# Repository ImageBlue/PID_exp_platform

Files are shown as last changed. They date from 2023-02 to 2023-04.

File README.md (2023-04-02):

# PID_exp_platform
## 某小组的大创项目

项目名称：基于开源硬件的水下推进器PID实验平台
A PID experiment platform based on open-sourced hardware.

## 项目的代码主要分为两部分：

### 上位机：OController

主要功能：显示实时流速（流速以推进器产生的水流冲击挡板，使挡板产生的**偏角**为依据）、与下位机有线或无线连接、对下位机PID参数和目标流速的设置

上位机的可运行程序已上传至项目的release，提供Windows版和DawningW第三方打包的MacOS版

### 下位机：

主要功能：控制推进器、响应上位机发来的请求  
下位机主要由外壳、shield、Arduino UNO、ESP32等各模块组成  
shield连接各个模块，~~外壳则进行保护包装~~  
下位机详见uno、esp32、shell、PCB文件夹

## 项目作者：

[*ImageBlue*](https://github.com/ImageBlue)

[*Bismark-bugger*](https://github.com/Bismark-bugger)

[*Silicon-t*](https://github.com/Silicon-t)

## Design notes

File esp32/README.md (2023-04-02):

大创项目的下位机  

该部分为esp32代码  
外设连接：推进器-D4   软串口-D23,D22   USB-TTL模块(不必须)-TXD,RXD,5V   串口   

*进度  
2023/2/10  完成与uno的软串口通讯测试，完成串口助手的通讯测试，完成MQTT基础通讯测试（未写入），完成推进器的驱动测试（未写入）  
2023/2/13  完成PID算法的移植，完成与上位机的串口初步调试，完成串口指令识别操作，完成推进器控制补充   
2023/3/6  完成MQTT代码移植，完成连接模式检查逻辑的编写，完成PID实机水下测试，完成与上位机包括MQTT和串口的完整通讯测试  
2023/4/3  卧槽版本大更新，但应该是最终版，~~鬼知道我们经历了什么~~

*更新日志  
2023/2/10  
-上传文件  核心代码：esp32_pro  硬件/软件串口模块：usart  软串口SoftwareSerial库：SoftwareSerial.h/.cpp  
完成与UNO的软串口连接通讯，可以接收并处理UNO发送的原始流速数据，真实流速值精确到0.01  
完成硬件串口通讯，此处用的是XCOM串口助手，可以进行发送实时流速值与接收设定的目标流速  
！！！！！注意：流速值指令格式 VELO int ，此处int为至多五位的整形，该值为实时流速值×100后的值，上位机接收时注意处理  
设定目标流速指令格式 VELO int ,此处int为至多三位的整形  
2023/2/13  
-上传文件  PID功能操作：command.ino  自创PID库文件：pid.h/.cpp（创建者[*Silicon-t*](https://github.com/Silicon-t)）  
-更新文件  核心代码：esp32_pro.ino  硬件/软件串口模块：usart.ino  
完成自创PID库的移植，采用C++编写，高度封装，PID流程已打包完成，使用command的run_pid函数即可  
加入推进器的控制，很简单，PWM输出即可  
更新串口指令识别，可以识别指令：手动自动切换、PID参数接收与处理，与上位机实现初步通讯测试  
优化了与UNO的软串口通讯的接收功能，用以解决随机出现的LoadStoreError  
2023/3/6  
-上传文件  MQTT驱动代码：mqtt_pro.ino  
-更新文件  核心代码：esp32_pro.ino  硬件/软件串口模块：usart.ino  
优化了PID参数更改指令的处理流程，解决了PID参数无法正常更改的重大bug  
完成MQTT部分代码移植，可以实现MQTT服务器连接、实时流速上传与上位机指令控制，指令格式与串口完全一致   
！！！！！注意：需要先启动树莓派的MQTT服务器终端，树莓派端使用的是mosquitto库，当然要是自己搭建了MQTT服务器终端  
！！！！！注意：使用时先改代码中mqtt_pro.ino的wifi账号与密码、MQTT服务器的IP与端口号，ESP32与服务器终端务必在一个局域网内   
ESP32启动后会进行连接方式检测，会进行MQTT与串口的轮询检测，对应的Connect指示灯会闪烁  
如果进行串口连接，请打开上位机后等待ESP32识别；如果进行MQTT连接，启动服务器后等待即可  
优化了回传实时流速的指令生成部分，便于调用，节约资源  
PID算法初步实机实验，算法在跑但跑的不是特别好，将会改进  
！！！！！注意：推进器由外部24V电源供电，请勿连接ESP32的3V3引脚，会导致ESP32损坏  
后续计划加入更多的指示灯与连接重置按键，敬请期待下次更新

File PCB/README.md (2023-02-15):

大创项目的shield设计文件  
包含：lcd_shield，board_shield  
使用立创EDA设计  

*立创eda打开方式  
解压嘉立创工程文件，里面有原理图与PCB的.json文件  
打开编辑器，通过：顶部菜单 - 文件 - 打开 - 立创EDA... ，选择 json 文件打开在编辑器，你可以保存文档进工程里面。

*进度   
2023/2/10   完成设计与焊接  

*更新日志  
2023/2/10  
上传文件  嘉立创工程文件：bjut_v2_20230210,bjut_v2_20230210  制板文件：Gerber_bjuts_v2,Gerber_PCB_lcd_tr  
bjut_v2：board_shield ，实现uno、esp、yf-s201、推进器等模块连接，注意5V供电  
lcd_tr：lcd_shield，实现LCD-1602连接，与board_shield的lcd排母对应，lcd的VL与可变电阻相连  

*BOM清单  
bjuts_v2：

| | Name | Designator | Footprint | Quantity |
| ---- | --- | --- | --- | --- |
| 1 | DC005-2.0MM | DC1 | DC-IN-TH_DC005 | 1 |
| 2 | 180Ω | R3 | R1206 | 1 |
| 3 | FC-2012UGK-520D5 | LED1 | LED0805-R-RD | 1 |
| 4 | PM254-1-16-Z-8.5 | LCD | HDR-TH_16P-P2.54-V-F-A | 1 |
| 5 | Header-Male-2.54_1x3  | YF-S201,P  | HDR-TH_3P-P2.54-V-M-1  | 2 |
| 6 | DSWB01LHGET | SW1 | SW-TH_DSWB01LHGET | 1 |
| 7 | 2.54-1*4P母 | USB-TTL | HDR-TH_4P-P2.54-V-F | 1 |
| 8 | Header-Male-2.54_1x10 | H3 | HDR-TH_10P-P2.54-V-M-1 | 1 |
| 9 | Header-Male-2.54_1x8  | H4,H5 | HDR-TH_8P-P2.54-V-M | 2 |
| 10 | Header-Male-2.54_1x6  | H6 | HDR-TH_6P-P2.54-V-M-1  | 1 |
| 11 | PM254-1-15-Z-8.5 | U2,U3 | HDR-TH_15P-P2.54-V-F | 2 |

lcd_tr：

| ID | Name | Designator | Footprint | Quantity |
| ---- | --- | --- | --- | --- |
| 1 | X6511WV-16H-C30D60 | H1 | HDR-TH_16P-P2.54-V-M | 1 |
| 2 | PM254-1-16-Z-8.5 | LCD1 | HDR-TH_16P-P2.54-V-F-A | 1 |
| 3 | 50Ω | R1 | RES-ADJ-TH_3P-L9.5-W4.9-P2.50-L_3296W | 1 |

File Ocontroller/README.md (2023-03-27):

# OController上位机

## 简介：

OController是大创项目的上位机，由Qt编写

如您所见，目前已大致完成，最新版本为v1.2.0，可运行程序已在release中放出

上位机具备**有线串口连接**和**无线MQTT连接**功能，在左侧连接模式框中进行参数设置和连接。

实验平台以挡板被水流冲击产生的偏角作为流速的依据，上位机右上角具备绘图区，可以绘制**实时角度-时间**图

上位机右下角用于设置PID参数和目标角度，以及其他控制操作

程序使用了QCharts库进行绘图，使用了QSerialPort和qtmqtt实现串口通信和MQTT通信，并将通信置于多线程中，减少通信与绘图之间的干扰

**注：**

在本地编译源代码需要自行下载并编译Qt的qtmqtt库：https://github.com/qt/qtmqtt

开发上位机的Qt版本为**5.14.2**，与其他版本Qt的函数调用可能有差异

## 通信格式：

| 通信格式 | 含义 |
| --- | --- |
| VELO *int* | 向下位机设置目标角度，数据类型**int** |
| PID P:*int* I:*int* D:*int* | 向下位机设置PID参数，数据类型为**一位float乘以10转int**，该操作会切换回手动模式 |
| AUTO | 启动下位机模糊PID模式，启用后下位机自动设置PID参数 |

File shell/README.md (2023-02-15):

大创项目的下位机的外壳  

使用solidwork设计，嘉立创三维猴进行3D打印

包含文件  顶层板与底层板设计文件及其对应stl文件：up，bottom  装配体文件：bjut

*进度  
2023/2/13  完成设计，已打印出成品  

*更新日志  
2023/2/13  
上传设计文件，打印完成  
顶层开窗，对应lcd、电源开关、推进器等模块连接  
前侧开窗，对应DC电源插座与ESP32观测口  
！！！注意安装方向，卡扣只有1mm厚度，务必顶层板带着shield拼装体一起安装  
圆孔与shield的固定孔对应，可以使用M3的长固定柱进行竖直方向的固定

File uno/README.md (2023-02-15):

大创项目的下位机

该部分为Arduino UNO的代码  
连接  水流速传感器YFS201-8,5V   软串口-A4,A5   LCD1602: RS-7 EN-6 D4:D7-5:2

*进度  
2023/2/10  UNO部分功能已经基本完成，完成流速值读取并处理，完成与ESP32的软串口通讯，完成LCD显示控制  
2023/2/13  更新软串口通讯方式，希望不会再出软串口的问题  

*更新日志  
2023/2/10  
上传文件  核心代码：uno_pro  
完成流速计驱动与读取，并通过软串口发送给ESP32，注意，该值经过×100处理，详情见ESP32部分  
LCD显示：第一行显示累计流量，第二行显示当前流速  
！！！注意：由于流速计的pulseIn函数是类似delay一样的函数，切忌再给uno添加其他不属于流速计范畴的功能，比如串口接收  
2023/2/13  
更新文件  核心代码：uno_pro  
更改了软串口的流速格式，用以解决ESP32的LoadStoreError  
完全关闭UNO的硬件串口通讯功能，请不要使用UNO硬件串口功能

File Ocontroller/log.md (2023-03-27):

## 更新日志：

v1.2.0-2023/3/27

由于流速计在实际环境中测量效果不佳，流速以挡板被水流冲击产生偏角作为流速的依据，替换了上位机中有关流速的相关文本，增加了对目标角度范围的限制

v1.1.1-2023/3/6

修复了多线程调度的错误

v1.1-2023/3/5

为适应下位机实际流速变化范围，将V-t图最大流速由100改为600

将V-t图时间间隔由0.5s改为0.2s

优化上位机控制指令，删去MANU指令

修复了一个多线程调度的错误

v1.0-2023/2/28

为关闭程序按钮更换了更加醒目的颜色，减少误触

完全实现了MQTT通信的功能

上位机全部功能已经完成

感谢[*DawningW*](https://github.com/DawningW)对MQTT功能实现的帮助

2023/2/11

实现了模糊PID的开关功能

添加了MQTT相关代码，但未经测试，未验证其是否可行

2023/1/12

修复了串口连接状态获取错误的问题

MQTT连接界面新增订阅主题和发布主题的文本框，为MQTT功能开发做准备

2023/1/4

在串口通信中引入了多线程，完全实现了上下位机之间的通信

2022/8/13

图表可以显示最新速率值

2022/8/2

修复了串口通信中，数据不能同时发送和接收的问题，完善串口通信功能

2022/7/31

新增不完善的串口写入功能：只是简单的串口写，未解决写数据时读数据丢失的问题，该功能有待完善

2022/7/30

优化了V-t图的显示：绘满整张图时，不再清空图像，而是坐标整体左移，使显示更具有连贯性

2022/7/29

新增串口接收下位机数据功能：上位机可以接收到来自下位机的 VELO int 格式的流速信息

新增V-t图绘制功能：上位机可以将接收到的实时流速数据绘制在图表上

修复了串口断开重连时，上位机不能正常接收数据的问题

2022/7/22

新增简单的串口读取功能

2022/7/21

新增窗口绘图：现在绘图区不再是一片空白，而是拥有了一张静态的V-t图

新增清空绘图功能

未选择有效串口时，点击连接串口，会有弹框提示

2022/7/20

新增串口连接和串口关闭功能

2022/7/18

新增搜索串口功能

连接选项框现在也已解除固定大小的限制

2022/7/15

新增自动、手动模式选择功能：您只能在手动模式下设置PID参数

新增参数设置功能：您可以在输入框中输入PID或V数值，按下按钮来更新数值

解除了固定窗口大小的限制

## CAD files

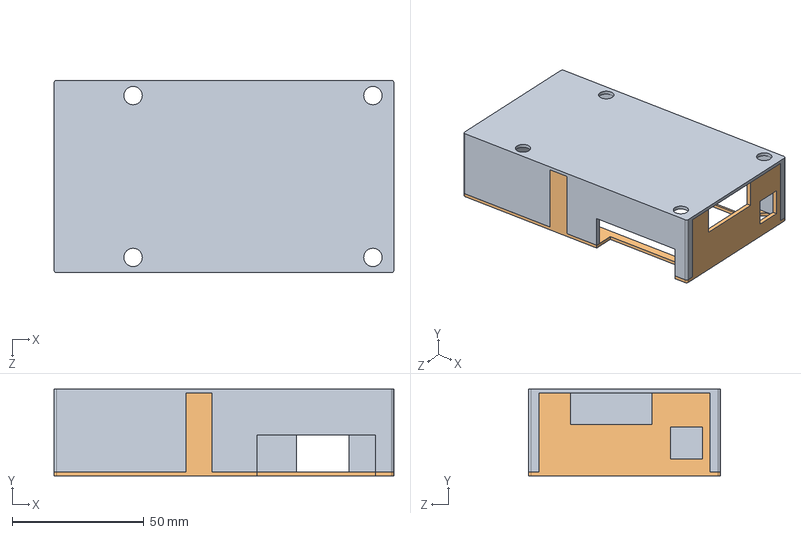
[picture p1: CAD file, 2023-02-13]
shell/bjut.SLDASM
129.0 x 33.0 x 73.0 mm
bottom
up

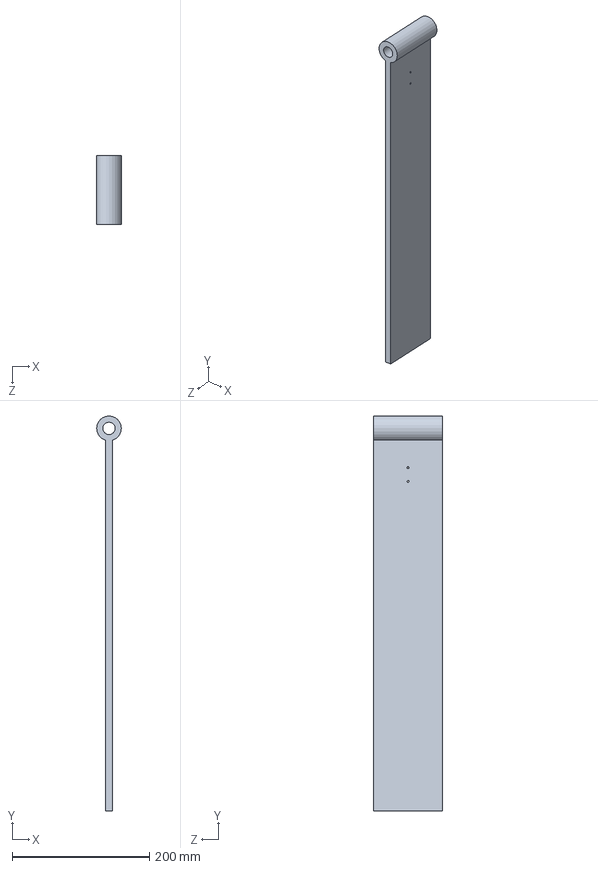
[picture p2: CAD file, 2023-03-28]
shell/backplate.SLDPRT
36.0 x 575.3 x 100.0 mm

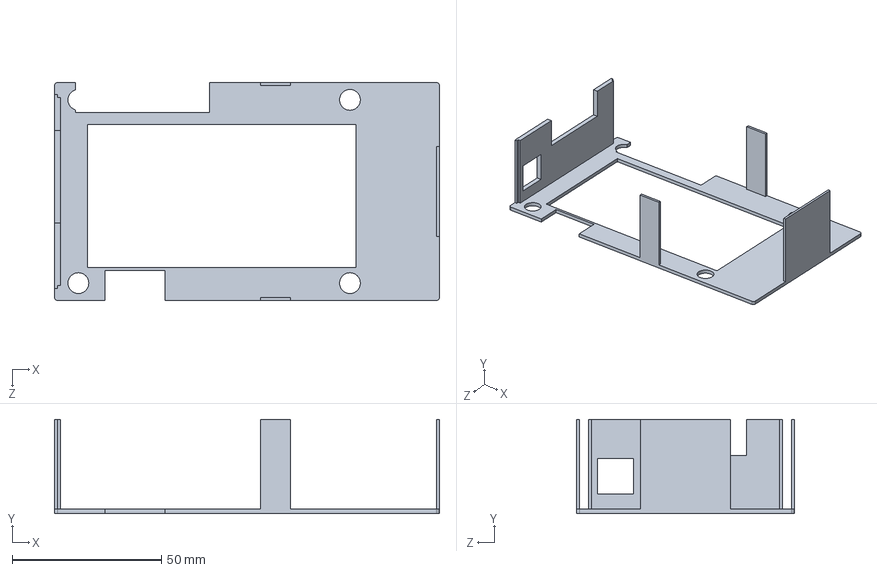
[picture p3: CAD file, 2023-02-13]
shell/up.SLDPRT
129.0 x 31.5 x 73.0 mm

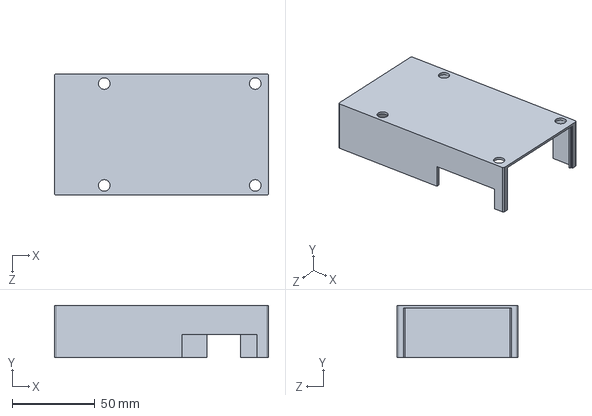
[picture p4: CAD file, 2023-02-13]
shell/bottom.SLDPRT
129.0 x 31.5 x 73.0 mm

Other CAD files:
shell/backplate.STL
shell/bottom.STL
shell/up.STL

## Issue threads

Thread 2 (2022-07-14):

窗口大小不应该固定

DawningW, 2022-07-14:
https://github.com/ImageBlue/PID_exp_platform/blob/7a654ca97a826899123f453b0e41e01f893bda63/OController/mainwindow.cpp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

最好不要把大小写死, 而是充分利用Qt的布局系统

不写死的原因主要是和分辨率有关, 如果有人还在用640\*480的上古显示器, 那么就没法完全显示750\*500的窗口(虽然不太可能), 所以最好不要写死, 而是能让用户自己调节

DawningW, 2022-08-01:
fixed

Closed 2022-08-01.

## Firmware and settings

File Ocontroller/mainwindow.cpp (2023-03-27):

#include "mainwindow.h"
#include "ui_mainwindow.h"
#include <iostream>
#include <QtSerialPort/QSerialPort>
#include <QtSerialPort/QSerialPortInfo>
#include <QTimer>
#include <QTime>
#include <QDebug>
#include <QBitArray>
#include <QMessageBox>
#include <QByteArray>
#include <QString>
#include <QThread>
#include <QtCore/QDateTime>
//#include <qmqtt.h>
#include <QtMqtt/qmqttclient.h>
//#include <QtMqtt/QtMqtt>

/******************************************初始化全局变量*********************************************/
bool isManu = true;                  //手动模式开关，默认手动模式
float fParaP = 1.0;                  //PID参数
float fParaI = 1.0;
float fParaD = 1.0;
int iParaV = 0;                      //初始流速
bool bSerialFlag = false;
bool bWirelessFlag = false;
int iAxisT = 0;
int iVelo;
double dVelo;
QByteArray baBuffer;
QString qstrSend;

MainWindow::MainWindow(QWidget *parent)
    : QMainWindow(parent)
    , ui(new Ui::MainWindow)
{
    /******************************************初始化变量**********************************************/
    //SerialPort = new QSerialPort;
    chart = new QChart();
    chartView = new QChartView(chart);
    AxisXT = new QValueAxis();
    AxisYV = new QValueAxis();
    sSeriesV = new QSplineSeries();
    //curTime = QDateTime::currentDateTime();
    //strTime = curTime.toString("hh:mm:ss");
    ConnectSerialTimer = new QTimer();
    writetimer = new QTimer();
    painttimer = new QTimer();
    ASerialPort = new AsyncSerialPort();
    AMqtt = new AsyncMQTT();
    //qDebug() << "UI Thread: " << QThread::currentThread();
    /******************************************初始化控件*********************************************/
    ui->setupUi(this);

    ui->ManuRButton->setChecked(true);

    ui->PlineEdit->setText("1.0");
    ui->IlineEdit->setText("1.0");
    ui->DlineEdit->setText("1.0");
    ui->VlineEdit->setText("0");

    ui->CloseSerialButton->setEnabled(false);
    ui->WLDisconnectButton->setEnabled(false);

    //绘图区控件
    //时间轴
    AxisXT->setTitleText(tr("时间/s"));                                  // y轴显示标题
    QFont FontX_T("Times",12,2,false);                                 //设置YL轴字体样式
    AxisXT->setTitleFont(FontX_T);
    AxisXT->setRange(0, 2);                                          // 范围
    AxisXT->setTickCount(11);                                         // 轴上点的个数
    QFont FontX("Times",10,2,false);                                   //设置YL轴字体样式
    AxisXT->setLabelsFont(FontX);

    //流速轴
    AxisYV->setTitleText(tr("角度/°"));                                  // y轴显示标题
    QFont FontYL_T("Times",12,2,false);                                //设置YL轴字体样式
    AxisYV->setTitleFont(FontYL_T);
    AxisYV->setRange(0, 50);                                          // 范围
    AxisYV->setTickCount(11);                                         // 轴上点的个数
    QFont FontYL("Times",10,2,false);                                  //设置YL轴字体样式
    AxisYV->setLabelsFont(FontYL);
    AxisYV->setLabelsColor(Qt::blue);
    AxisYV->setGridLineVisible(true);                                 // 隐藏背景网格Y轴框线

    // 图表
    chart->setAnimationOptions(QChart::SeriesAnimations);              // 动画方式

    // 图表视图
    chartView->chart()->setTitle(tr("角度-时间 图，实时角度：NULL"));       // 设置标题
    chartView->setRenderHint(QPainter::Antialiasing);                  // 反锯齿绘制
    chartView->chart()->addSeries(sSeriesV);                           // 添加线段
    chartView->chart()->setTheme(QChart::ChartThemeHighContrast);      // 设置主题
    QFont Font_Title("Times",11,2,false);
    chartView->chart()->setTitleFont(Font_Title);
    chartView->chart()->addAxis(AxisXT, Qt::AlignBottom);              // 设置X轴位置
    chartView->chart()->addAxis(AxisYV, Qt::AlignLeft);               // 设置YV轴位置
    // 流速数据线段
    sSeriesV->setPen(QPen(Qt::blue, 2, Qt::SolidLine));                 // 设置线段pen
    sSeriesV->attachAxis(AxisXT);                                      // 线段依附的X轴
    sSeriesV->attachAxis(AxisYV);                                     // 线段依附的YT轴
    sSeriesV->setName(tr("角度"));                                      // 线段名称，在图例会显示
    sSeriesV->setPointsVisible(true);

    // 图例
    chart->legend()->setVisible(true);                                  // 图例显示
    chart->legend()->setAlignment(Qt::AlignTop);                        // 图例向下居中

    // 将图表扔进QWidget
    ui->graphicsView->setChart(chart);                                  // 将图表对象设置到graphicsView上进行显示
    ui->graphicsView->setRenderHint(QPainter::Antialiasing);            // 设置渲染：抗锯齿，如果不设置那么曲线就显得不平滑
}

MainWindow::~MainWindow()
{
    delete ui;
    on_CloseButton_clicked();
}


void MainWindow::on_CloseButton_clicked()
{
    ASerialPort->~AsyncSerialPort();
    exit(0);
}


void MainWindow::on_SetNewButton_clicked()
{
    QString qstrP, qstrI, qstrD;          //读取LineEdit中的字符串
    qstrP.clear();
    qstrI.clear();
    qstrD.clear();

    qstrP = ui->PlineEdit->text();
    qstrI = ui->IlineEdit->text();
    qstrD = ui->DlineEdit->text();

    float fTempP, fTempI, fTempD;         //字符串转float（暂存，等待合法性判断）
    fTempP = qstrP.toFloat();
    fTempI = qstrI.toFloat();
    fTempD = qstrD.toFloat();

    int iTempP, iTempI, iTempD;

    iTempP = fTempP*10;
    iTempI = fTempI*10;
    iTempD = fTempD*10;

    if(iTempP >= 0 && iTempI >= 0 && iTempD >= 0)  //数据合法，更新参数
    {
        fParaP = fTempP;
        fParaI = fTempI;
        fParaD = fTempD;
        //qDebug() << "P:" << fParaP << " I:" << fParaI << " D:" << fParaD;
        //TODO:串口发送参数
        qstrP = QString::number(iTempP);
        qstrI = QString::number(iTempI);
        qstrD = QString::number(iTempD);
        //qDebug() << qstrP << qstrI << qstrD;
        qstrSend.clear();
        qstrSend = "PID P:";
        qstrSend.append(qstrP);
        qstrSend.append(" I:");
        qstrSend.append(qstrI);
        qstrSend.append(" D:");
        qstrSend.append(qstrD);
        //qDebug() << qstrSend.toLatin1();

        if(bSerialFlag == true)
        {
            emit Send_to_SerialPort(qstrSend);
        }
        else if(bWirelessFlag == true)
        {
            //QString PubTopic = ui->PubEdit->text();
            emit Send_to_MQTT(qstrSend);
        }
        else
        {
            QMessageBox::information(this,tr("写入失败"),tr("串口与无线均未连接到下位机！"),QMessageBox::Ok);
        }
    }
    else
    {
        QMessageBox::information(this,tr("写入失败"),tr("PID参数非法！"),QMessageBox::Ok);
    }
}


void MainWindow::on_VNewButton_clicked()
{
    QString qstrV;                       //读取LineEdit中的字符串
    qstrV.clear();

    qstrV = ui->VlineEdit->text();       //字符串转int（暂存，等待合法性判断）

    int iTempV = qstrV.toInt();

    if(iTempV >= 0 && iTempV <= 45)                       //数据合法，更新参数
    {
        iParaV = iTempV;
        //qDebug() << "Velocity:" << iParaV;
        //TODO:串口发送参数
        qstrSend.clear();
        qstrSend = "VELO ";
        qstrSend.append(qstrV);
        //qDebug() << qstrSend.toLatin1();

        if(bSerialFlag == true)
        {
            emit Send_to_SerialPort(qstrSend);
        }
        else if(bWirelessFlag == true)
        {
            emit Send_to_MQTT(qstrSend);
        }
        else
        {
            QMessageBox::information(this,tr("写入失败"),tr("串口与无线均未连接到下位机！"),QMessageBox::Ok);
        }
    }
    else
    {
        QMessageBox::information(this,tr("写入失败"),tr("角度数值非法！"),QMessageBox::Ok);
    }
}


void MainWindow::on_SearchSeiralButton_clicked()
{
    //查找可用的串口
    foreach(const QSerialPortInfo &info, QSerialPortInfo::availablePorts())
    {
        QSerialPort serial;
        serial.setPort(info);                           //设置串口
        if(serial.open(QIODevice::ReadWrite))
        {
            ui->COMCBox->addItem(serial.portName());    //显示串口name
            serial.close();
        }
    }
}


void MainWindow::on_ConnectSerialButton_clicked()
{
    sleep(100);                                         //延时100ms
    QString curText = ui->COMCBox->currentText();                  //串口名
    int BaudRate = ui->BaudCBox->currentText().toInt();            //波特率
    QString EndBit = ui->EndCBox->currentText();                   //停止位
    int DataBit = ui->DataCBox->currentText().toInt();             //数据位
    QString CheckBit = ui->CheckCBox->currentText();               //校验位

    //SerialPort->close();
    ASerialPort->Init_Port(curText, BaudRate, EndBit, DataBit, CheckBit);

    bWirelessFlag = false;

    if(ASerialPort->IsConnected() == true)
    {
        bSerialFlag = true;
    }

    if(bSerialFlag == true)
    {
        qDebug()<< "SerialPort Connected";

        connect(ASerialPort, &AsyncSerialPort::Rec_Data, this, &MainWindow::SerialPort_Receive, Qt::QueuedConnection);
        connect(ASerialPort, &AsyncSerialPort::Rec_Data, this, &MainWindow::Paint_Data, Qt::QueuedConnection);
        connect(this, &MainWindow::Send_to_SerialPort, ASerialPort, &AsyncSerialPort::Write_Data, Qt::QueuedConnection);

        ui->CloseSerialButton->setEnabled(true);
        ui->ConnectSerialButton->setEnabled(false);

        ui->WLConnectButton->setEnabled(false);
    }
    else
    {
        QMessageBox::information(this,tr("串口通信错误"),tr("请检查连接与参数设置！"),QMessageBox::Ok);
        return;
    }
}


void MainWindow::on_CloseSerialButton_clicked()
{
    ASerialPort->Disconnect_Serial();

    disconnect(ASerialPort, &AsyncSerialPort::Rec_Data, this, &MainWindow::SerialPort_Receive);
    disconnect(ASerialPort, &AsyncSerialPort::Rec_Data, this, &MainWindow::Paint_Data);
    disconnect(this, &MainWindow::Send_to_SerialPort, ASerialPort, &AsyncSerialPort::Write_Data);

    bSerialFlag = false;
    ui->CloseSerialButton->setEnabled(false);
    ui->ConnectSerialButton->setEnabled(true);

    ui->WLConnectButton->setEnabled(true);
}


void MainWindow::sleep(int msec)
{
    QTime dieTime = QTime::currentTime().addMSecs(msec);
    while( QTime::currentTime() < dieTime)
        QCoreApplication::processEvents(QEventLoop::AllEvents, 100);
}


void MainWindow::SerialPort_Receive(QByteArray buffer)
{
    baBuffer.clear();
    baBuffer.append(buffer);
    //qDebug() << "main thread heard: " << baBuffer;
}


void MainWindow::on_ClearButton_clicked()
{
    sSeriesV->clear();
    iAxisT = 0;

    AxisXT->setRange(0, 2);
}

void MainWindow::Paint_Data()
{
    Sleep(15);
    QByteArray baStat, baVelo;
    if(bSerialFlag == true || bWirelessFlag == true)
    {
        baStat = baBuffer.mid(0,4);
        baVelo = baBuffer.mid(5,4);
        qDebug()<< baBuffer << baStat << baVelo;
        if(baStat == "VELO")
        {
            iVelo = baVelo.toInt();
            dVelo = iVelo/100.0;
            //qDebug() << "Plot" << iAxisT << ',' << iVelo;
            sSeriesV->append(iAxisT/5.0,dVelo);
            iAxisT++;
            if(iAxisT > 10)
            {
                AxisXT->setRange((iAxisT - 10)/5.0, iAxisT/5.0);
            }
            chartView->chart()->setTitle(tr("角度-时间 图，实时角度：")+QString::number(dVelo, 'f', 2));
        }
        else if(baStat == "CALL")
        {
            qstrSend.clear();
            qstrSend = "ANSW";

            if(bWirelessFlag == false && bSerialFlag == true)  //串口回复
            {
                emit Send_to_SerialPort(qstrSend);
                qDebug() << "SerialPort Answer";
            }
        }
    }
    baBuffer.clear();
}

void MainWindow::on_WLConnectButton_clicked()
{
    QString HostName = ui->IPEdit->text();
    int MPort = ui->PortEdit->text().toInt();
    QString SubTopic = ui->SubEdit->text();
    QString PubTopic = ui->PubEdit->text();
    qDebug() << HostName << MPort << SubTopic << PubTopic;

    AMqtt->Init_MQTT(HostName, MPort, SubTopic, PubTopic);

    bSerialFlag = false;

    sleep(1000);
    if(AMqtt->IsConnected() == true)
    {
        bWirelessFlag = true;
    }

    if(bWirelessFlag == true)
    {
        connect(AMqtt, &AsyncMQTT::Rec_Data, this, &MainWindow::MQTT_Receive, Qt::QueuedConnection);
        connect(AMqtt, &AsyncMQTT::Rec_Data, this, &MainWindow::Paint_Data, Qt::QueuedConnection);
        connect(this, &MainWindow::Send_to_MQTT, AMqtt, &AsyncMQTT::Write_Data, Qt::QueuedConnection);

        ui->WLConnectButton->setEnabled(false);
        ui->WLDisconnectButton->setEnabled(true);

        ui->ConnectSerialButton->setEnabled(false);
    }
    else
    {
        QMessageBox::information(this,tr("MQTT通信错误"),tr("请检查连接与参数设置！"),QMessageBox::Ok);
        return;
    }
}


void MainWindow::on_WLDisconnectButton_clicked()
{
    bWirelessFlag = false;

    AMqtt->Disconnect_MQTT();

    disconnect(AMqtt, &AsyncMQTT::Rec_Data, this, &MainWindow::MQTT_Receive);
    disconnect(AMqtt, &AsyncMQTT::Rec_Data, this, &MainWindow::Paint_Data);
    disconnect(this, &MainWindow::Send_to_MQTT, AMqtt, &AsyncMQTT::Write_Data);

    ui->WLConnectButton->setEnabled(true);
    ui->WLDisconnectButton->setEnabled(false);

    ui->ConnectSerialButton->setEnabled(true);
}

void MainWindow::MQTT_Receive(QByteArray buffer)
{
    baBuffer.clear();
    baBuffer.append(buffer);
    //qDebug() << "main thread heard: " << baBuffer;
}

void MainWindow::on_ManuRButton_clicked()
{
    QString qstrP, qstrI, qstrD;          //读取LineEdit中的字符串
    qstrP.clear();
    qstrI.clear();
    qstrD.clear();

    qstrP = ui->PlineEdit->text();
    qstrI = ui->IlineEdit->text();
    qstrD = ui->DlineEdit->text();

    float fTempP, fTempI, fTempD;         //字符串转float（暂存，等待合法性判断）
    fTempP = qstrP.toFloat();
    fTempI = qstrI.toFloat();
    fTempD = qstrD.toFloat();

    int iTempP, iTempI, iTempD;

    iTempP = fTempP*10;
    iTempI = fTempI*10;
    iTempD = fTempD*10;

    if(iTempP >= 0 && iTempI >= 0 && iTempD >= 0)  //数据合法，更新参数
    {
        fParaP = fTempP;
        fParaI = fTempI;
        fParaD = fTempD;
        //qDebug() << "P:" << fParaP << " I:" << fParaI << " D:" << fParaD;
        //TODO:串口发送参数
        qstrP = QString::number(iTempP);
        qstrI = QString::number(iTempI);
        qstrD = QString::number(iTempD);
        //qDebug() << qstrP << qstrI << qstrD;
        qstrSend.clear();
        qstrSend = "PID P:";
        qstrSend.append(qstrP);
        qstrSend.append(" I:");
        qstrSend.append(qstrI);
        qstrSend.append(" D:");
        qstrSend.append(qstrD);

        if(bWirelessFlag == false && bSerialFlag == true)  //串口发送
        {
            emit Send_to_SerialPort(qstrSend);
            qDebug() << "SerialPort MANU";
        }
        else if(bSerialFlag == false && bWirelessFlag == true)    //MQTT发送
        {
            emit Send_to_MQTT(qstrSend);
            qDebug() << "MQTT MANU";
        }
        else
        {
            qDebug() << "No Connection";
        }

        isManu = true;
        ui->SetNewButton->setEnabled(isManu);
    }
    else
    {
        isManu = false;
        ui->ManuRButton->setChecked(false);
        ui->AutoRButton->setChecked(true);
        QMessageBox::information(this,tr("写入失败"),tr("PID参数非法！"),QMessageBox::Ok);
    }
}


void MainWindow::on_AutoRButton_clicked()
{
    isManu = false;
    ui->SetNewButton->setEnabled(isManu);

    qstrSend.clear();
    qstrSend = "AUTO";

    if(bWirelessFlag == false && bSerialFlag == true)  //串口发送
    {
        emit Send_to_SerialPort(qstrSend);
        qDebug() << "SerialPort AUTO";
    }
    else if(bSerialFlag == false && bWirelessFlag == true)    //MQTT发送
    {
        emit Send_to_MQTT(qstrSend);
        qDebug() << "MQTT AUTO";
    }
    else
    {
        qDebug() << "No Connection";
    }
}

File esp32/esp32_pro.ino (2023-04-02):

/**
 * @file ESP-CAM.ino
 * @author 杨家麒 (2313108048@mail.dlut.edu.cn)
 * @brief 基于开源硬件的水下推进器的PID实验平台 ESP-32部分
 * @version 1.0
 * @date 2023-2-8
 * 
 * @copyright Copyright (c) 2023 杨家麒, 刘崇胜, 唐晨晖
 */
#include<WiFi.h>
#include<PubSubClient.h>
#include "soc/rtc_cntl_reg.h"
#include "soc/soc.h"
#include "SoftwareSerial.h"
#include <HardwareSerial.h>    //导入ESP32串口操作库,使用这个库我们可以把串口映射到其他的引脚上使用
#include "pid.h"

SoftwareSerial SerialUno(22, 23);  //rx tx
pid pid1;                             //PID初始化,设置初始值
command cmd;
WiFiClient espClient;                     // 定义wifiClient实例
PubSubClient client(espClient);          // 定义PubSubClient的实例

int connect_flag = 0; //0-no 1-uart 2-mqtt
int led_flag = 0; //0 or 1023
char temp_ret[10]; //mqtt
char to_uno[9];

int whether_auto = 1;
int target_velo = 0;  //目标流速
float velo = 0.0;
int velo_i = 0;
float p, i, d;
long int pwmval = 0;  //推进器

uint8_t p_pin = 4;
uint8_t p_ch=1; 
uint8_t led_pinb = 2;
uint8_t led_chb = 2;
uint8_t mode_pin = 15;
uint8_t mode_ch = 3;
const int buttonPin = 5;     // the number of the pushbutton pin
int buttonState = 0;         // variable for reading the pushbutton status

void check_connect()  //连接检测
{
  int c=0;
  wifi_connect();
  mqtt_connect();
  for(c=0;c<10;c++)
  {
    Serial.println("CALL");
    delay(200);
    led_flag = (led_flag==0) ? 1023 : 0;
    ledcWrite(led_chb, led_flag); 
    read_usart_pc();
    if(connect_flag==1) break;
  }

  if(connect_flag == 1)
    ledcWrite(led_chb, 0);  //串口
  else if(connect_flag == 2)
    ledcWrite(led_chb, 1023);  //mqtt
}

void write_temp()
{
  temp_ret[0]='V';
  temp_ret[1]='E';
  temp_ret[2]='L';
  temp_ret[3]='O';
  temp_ret[4]=' ';
  temp_ret[5]=velo_i/1000+48;
  temp_ret[6]=(velo_i/100)%10+48;
  temp_ret[7]=(velo_i/10)%10+48;
  temp_ret[8]=velo_i%10+48;
}

void setup() 
{
  WRITE_PERI_REG(RTC_CNTL_BROWN_OUT_REG, 0); //disable brownout detector
  
  Serial.begin(115200);
  SerialUno.begin(115200);

  //pinMode(buttonPin, INPUT);

  ledcSetup(p_ch, 50, 20);
  ledcAttachPin(p_pin, p_ch);
  ledcWrite(p_ch, 78642);

  ledcSetup(mode_ch, 1000, 10); 
  ledcAttachPin(mode_pin, mode_ch);
  ledcWrite(mode_ch, 1023);

  ledcSetup(led_chb, 1000, 10); 
  ledcAttachPin(led_pinb, led_chb);
  ledcWrite(led_chb, 1023);
}

void loop() 
{
  if(!connect_flag)
    check_connect();
  else
  {
    if(connect_flag == 1)
      read_usart_pc();
    else if(connect_flag == 2)
      client.loop();
      
    read_usart_uno();
    write_temp();
    
    if(connect_flag == 1)
      Serial.println(temp_ret);
    else if(connect_flag == 2)
      client.publish("Callback",temp_ret);
    memset(temp_ret,'\0',sizeof(temp_ret));
    
    if(whether_auto) 
      pid1.get_pid(p, i, d);
    if(whether_auto) 
      ledcWrite(mode_ch, 1023);
    else 
      ledcWrite(mode_ch, 0);

    //buttonState = digitalRead(buttonPin);
    //if(!buttonState)
      //connect_flag = 0;
    //else
      //connect_flag = 1;
      
    cmd.run_pid(pid1);
    //Serial.println(pwmval);
    ledcWrite(1, pwmval);   //推进器
    delay(200);
  }
}

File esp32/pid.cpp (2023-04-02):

#include "pid.h"
#include<Arduino.h>
using namespace std;
extern int whether_auto;

void pid::set_pid(float p, float i, float d) {
  kp = p;
  ki = i;
  kd = d;
}

//设置target目标(流速)值
void pid::set_target(float velotury) {
  target = velotury;
}

void pid::get_pid(float &p, float &i, float &d){
  p = kp;
  i = ki;
  d = kd;
}

//pid实现,核心算法
float pid::pid_realize(/*float velotury*/) {
  //target = velotury;                                                                //设定目标值
  err = target - actual;                                                        //计算差值
  err_c = err - err_last;
  if (whether_auto)
    fuzzy_pid();
  integral += err;                                                              //累积积分值
  output = kp * err + ki * integral + kd * (err - err_last);                    //通过PID计算输出值
  err_last = err;
  float pwm = 78642 - output*600;                                                                //差值记录
  if(pwm > output_max)
    pwm = output_max;
  if(pwm < output_min)
    pwm = output_min;                                        //算的，感觉行，回头可能会改（看水下实验结果）
  return pwm;                                                                 //返回输出值
}

//获取当前速度值
float pid::get_output() {                                                         //目前代码仅用于作测试
  return output;
}

float pid::set_actual(float act_velo) {
  actual = act_velo;
  return actual;
}

float pid::read_actual(){
  return actual;
}

void pid::get_grad_membership(float qerr, float qerr_c) {
  if (qerr > e_membership_values[0] && qerr < e_membership_values[6])
  {
    for (int i = 0; i < num_area - 2; i++)
    {
      if (qerr >= e_membership_values[i] && qerr <= e_membership_values[i + 1])
      {
        e_gradmembership[0] = -(qerr - e_membership_values[i + 1]) / (e_membership_values[i + 1] - e_membership_values[i]);
        e_gradmembership[1] = 1 + (qerr - e_membership_values[i + 1]) / (e_membership_values[i + 1] - e_membership_values[i]);
        e_grad_index[0] = i;
        e_grad_index[1] = i + 1;
        break;
      }
    }
  }
  else if (qerr <= e_membership_values[0])
  {
    e_gradmembership[0] = 1;
    e_gradmembership[1] = 0;
    e_grad_index[0] = 0;
    e_grad_index[1] = -1;
  }
  else
  {
    e_gradmembership[0] = 1;
    e_gradmembership[1] = 0;
    e_grad_index[0] = 6;
    e_grad_index[1] = -1;
  }

  if (qerr_c > ec_membership_values[0] && qerr_c < ec_membership_values[6])
  {
    for (int i = 0; i < num_area - 2; i++)
    {
      if (qerr_c >= ec_membership_values[i] && qerr_c <= ec_membership_values[i + 1])
      {
        ec_gradmembership[0] = -(qerr_c - ec_membership_values[i + 1]) / (ec_membership_values[i + 1] - ec_membership_values[i]);
        ec_gradmembership[1] = 1 + (qerr_c - ec_membership_values[i + 1]) / (ec_membership_values[i + 1] - ec_membership_values[i]);
        ec_grad_index[0] = i;
        ec_grad_index[1] = i + 1;
        break;
      }
    }
  }
  else if (qerr_c <= ec_membership_values[0])
  {
    ec_gradmembership[0] = 1;
    ec_gradmembership[1] = 0;
    ec_grad_index[0] = 0;
    ec_grad_index[1] = -1;
  }
  else
  {
    ec_gradmembership[0] = 1;
    ec_gradmembership[1] = 0;
    ec_grad_index[0] = 6;
    ec_grad_index[1] = -1;
  }
}

void pid::get_sum_grad()
{
  for (int i = 0; i <= num_area - 1; i++)
  {
    KpgradSums[i] = 0;
    KigradSums[i] = 0;
    KdgradSums[i] = 0;
  }
  for (int i = 0; i < 2; i++)
  {
    if (e_grad_index[i] == -1)
    {
      continue;
    }
    for (int j = 0; j < 2; j++)
    {
      if (ec_grad_index[j] != -1)
      {
        int indexKp = Kp_rule_list[e_grad_index[i]][ec_grad_index[j]] + 3;
        int indexKi = Ki_rule_list[e_grad_index[i]][ec_grad_index[j]] + 3;
        int indexKd = Kd_rule_list[e_grad_index[i]][ec_grad_index[j]] + 3;
        //gradSums[index] = gradSums[index] + (e_gradmembership[i] * ec_gradmembership[j])* Kp_rule_list[e_grad_index[i]][ec_grad_index[j]];
        KpgradSums[indexKp] += (e_gradmembership[i] * ec_gradmembership[j]);
        KigradSums[indexKi] += (e_gradmembership[i] * ec_gradmembership[j]);
        KdgradSums[indexKd] += (e_gradmembership[i] * ec_gradmembership[j]);
      }
      else
      {
        continue;
      }
    }
  }
}

void pid::auto_set_pid()
{
  float qdetail_kp = 0;               //增量kp对应论域中的值
  float qdetail_ki = 0;               //增量ki对应论域中的值
  float qdetail_kd = 0;               //增量kd对应论域中的值
  for (int i = 0; i < num_area - 1; i++)
  {
    qdetail_kp += kp_menbership_values[i] * KpgradSums[i];
    qdetail_ki += ki_menbership_values[i] * KigradSums[i];
    qdetail_kd += kd_menbership_values[i] * KdgradSums[i];
  }
  kp += inverse_quantization(kp_max, kp_min, qdetail_kp);
  ki += inverse_quantization(ki_max, ki_min, qdetail_ki);
  kd += inverse_quantization(kd_max, kd_min, qdetail_kd);
  if (kp < 0)
    kp = 0;
  if (ki < 0)
    ki = 0;
  if (kd < 0)
    kd = 0;
}


void pid::fuzzy_pid() {
  float qerro = quantization(err_max, err_min, err);
  float qerro_c = quantization(errc_max, errc_min, err_c);
  get_grad_membership(qerro, qerro_c);
  get_sum_grad();
  auto_set_pid();
}

float pid::quantization(float maximum, float minimum, float x)
{
  float qvalues = 6.0 * (x - minimum) / (maximum - minimum) - 3;
  return qvalues;
}


float pid::inverse_quantization(float maximum, float minimum, float qvalues)
{
  float x = (maximum - minimum) * (qvalues + 3) / 6 + minimum;
  return x;
}

void pid::set_auto() {
  auto_pid = !auto_pid;
  if (auto_pid)
    Serial.println("Enable fuzzy_pid.");
  else
    Serial.println("Disable fuzzy_pid");
}

bool pid::read_auto(){
  return auto_pid;
}

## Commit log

2022-07-15 Update mainwindow.cpp
    添加了通过LineEdit和PushButton输入PID和V参数的功能
2022-07-15 Update OController
    新增按钮设置参数功能
    解除固定窗口大小的限制
2022-07-29 Add functions to receive velocity data and paint
2022-07-30 Optimize Velocity-time chart
2022-08-13 Add last velocity display function
2023-03-27 Changed the method of measuring velocity
2023-03-28 Add back plate STL file
    [backplate.SLDPRT, backplate.STL]
